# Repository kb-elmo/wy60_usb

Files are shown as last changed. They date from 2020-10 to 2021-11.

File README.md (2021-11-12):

# WY-60 USB

[][cc-by-nc-sa]
<a href="https://ko-fi.com/kb_elmo">kofibadge</a>

## This project is completed and will not get updated anymore.

### QMK compatible drop-in replacement PCB for the Wyse ASCII WY-60 keyboard
The PCB is built entirely with THT parts to keep a somewhat "vintage" look to it and it uses the fullsize 40-pin DIP package ATmega32A.
The controller is placed in the exact same location as the one on the original PCB.




### Partslist
 |Count|Part|
 |-|-|
 |1|ATmega32A 40 pin DIP (32L works too)|
 |1|40 pin DIP socket (optional but highly recommended)|
 |1|2x3 pin header 2.54mm (for ISP flashing)|
 |1|USB Mini port 5pin THT|
 |1|500 mA polyfuse|
 |2|6mm momentary push buttons|
 |1|16 MHz quarz crystal|
 |1|4.7 uF electrolytic capacitor|
 |2|100 nF ceramic disk capacitor|
 |2|22 pF ceramic disk capacitor|
 |1|10 kΩ resistor|
 |2|68 Ω resistor|
 |1|1.5 kΩ resistor|
 |2|3.6 V zener diode (DO-35 BZX55C3V6)|
 |101|universal switching diode (DO-35 1N4148)|

#### Some pictures of the first finished PCB
(https://i.imgur.com/SexuyVJ.jpg) (https://i.imgur.com/DevIs6e.jpg)
(https://i.imgur.com/V66OB8a.jpg) (https://i.imgur.com/2M1VHWP.jpg)
(https://i.imgur.com/meGhRla.jpg) (https://i.imgur.com/xnp9PsB.jpg)

The Case requires some modification to make the new USB port fit.  
Unfortunately the original cable cutout sits in a position where it was not possible to use it for the USB port.

---
This work is licensed under a
[Creative Commons Attribution-NonCommercial-ShareAlike 4.0 International License][cc-by-nc-sa].

[][cc-by-nc-sa]

[cc-by-nc-sa]: http://creativecommons.org/licenses/by-nc-sa/4.0/
[cc-by-nc-sa-image]: https://licensebuttons.net/l/by-nc-sa/4.0/88x31.png
[cc-by-nc-sa-shield]: https://img.shields.io/badge/License-CC%20BY--NC--SA%204.0-lightgrey.svg

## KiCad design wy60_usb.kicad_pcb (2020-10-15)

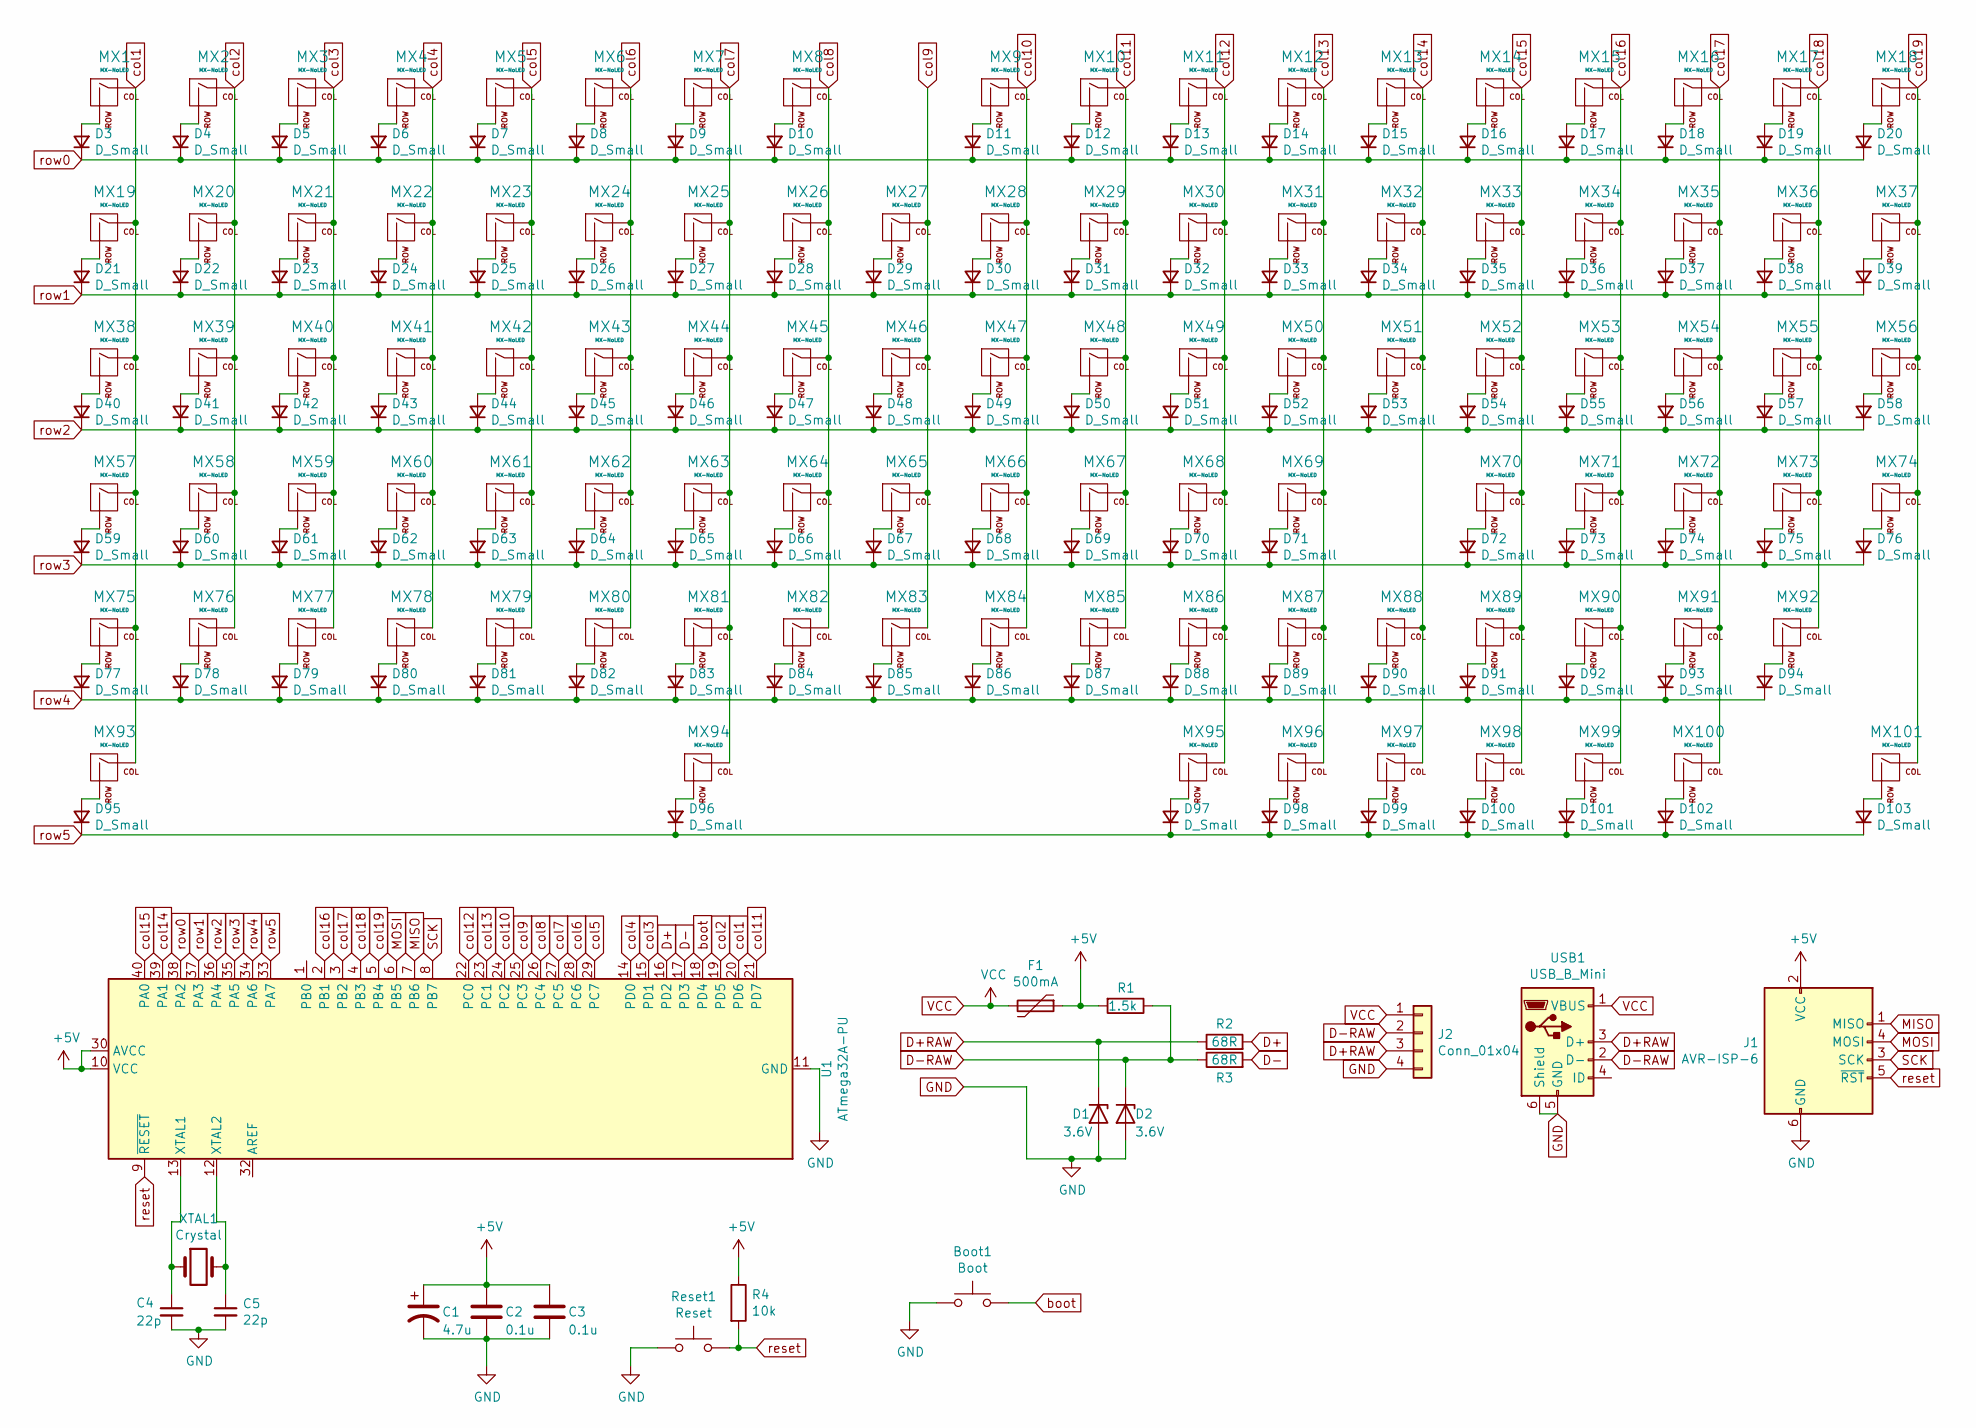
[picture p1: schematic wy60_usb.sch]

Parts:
Boot1: Boot; SW_PUSH_6mm
C1: 4.7u; CP_Radial_D4.0mm_P1.50mm
C2, C3: 0.1u; C_Disc_D3.0mm_W2.0mm_P2.50mm
C4, C5: 22p; C_Disc_D6.0mm_W2.5mm_P5.00mm
D1, D2: 3.6V; D_DO-35_SOD27_P7.62mm_Horizontal
D3, D4, D5, D6, D7, D8, D9, D10, D11, D12, D13, D14, D15, D16, D17, D18, D19, D20, D21, D22, D23, D24, D25, D26, D27, D28, D29, D30, D31, D32, D33, D34, D35, D36, D37, D38, D39, D40, D41, D42, D43, D44, D45, D46, D47, D48, D49, D50, D51, D52, D53, D54, D55, D56, D57, D58, D59, D60, D61, D62, D63, D64, D65, D66, D67, D68, D69, D70, D71, D72, D73, D74, D75, D76, D77, D78, D79, D80, D81, D82, D83, D84, D85, D86, D87, D88, D89, D90, D91, D92, D93, D94, D95, D96, D97, D98, D99, D100, D101, D102, D103: D_Small; D_DO-35_SOD27_P7.62mm_Horizontal
F1: 500mA; Fuse_Littelfuse_395Series
J1: AVR-ISP-6; PinHeader_2x03_P2.54mm_Horizontal
J2: Conn_01x04; JST_PH_S4B-PH-K_1x04_P2.00mm_Horizontal
MX1, MX2, MX3, MX4, MX5, MX6, MX7, MX8, MX9, MX10, MX11, MX12, MX13, MX14, MX15, MX16, MX17, MX18, MX19, MX20, MX21, MX22, MX23, MX24, MX25, MX26, MX27, MX28, MX29, MX30, MX31, MX33, MX34, MX35, MX36, MX37, MX39, MX40, MX41, MX42, MX43, MX44, MX45, MX46, MX47, MX48, MX49, MX50, MX51, MX53, MX54, MX55, MX56, MX58, MX59, MX60, MX61, MX62, MX63, MX64, MX65, MX66, MX67, MX68, MX70, MX71, MX72, MX73, MX74, MX75, MX77, MX78, MX79, MX80, MX81, MX82, MX83, MX84, MX85, MX86, MX88, MX89, MX90, MX91, MX92, MX95, MX96, MX97, MX98, MX100: MX-NoLED; MXOnly-1U-NoLED
MX32, MX57: MX-NoLED; MXOnly-1.75U-NoLED
MX38, MX87: MX-NoLED; MXOnly-1.5U-NoLED
MX52, MX76: MX-NoLED; MXOnly-1.25U-NoLED
MX69, MX93, MX99, MX101: MX-NoLED; MXOnly-2U-NoLED-NoStabilizer
MX94: MX-NoLED; MXOnly-9U-NoLED
R1: 1.5k; R_Axial_DIN0207_L6.3mm_D2.5mm_P10.16mm_Horizontal
R2, R3: 68R; R_Axial_DIN0207_L6.3mm_D2.5mm_P10.16mm_Horizontal
R4: 10k; R_Axial_DIN0207_L6.3mm_D2.5mm_P10.16mm_Horizontal
Reset1: Reset; SW_PUSH_6mm
U1: ATmega32A-PU; DIP-40_W15.24mm_Socket
USB1: USB_B_Mini; USB_Mini
XTAL1: Crystal; Crystal_HC49-4H_Vertical

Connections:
+5V: C1.1, C2.1, C3.1, F1.1, J1.2 (VCC), R1.2, R4.1, U1.10 (VCC), U1.30 (AVCC)
D+: R2.2, U1.16 (PD2)
D+RAW: D1.1 (K), J2.3, R2.1, USB1.3 (D+)
D-: R3.2, U1.17 (PD3)
D-RAW: D2.1 (K), J2.2, R1.1, R3.1, USB1.2 (D-)
GND: Boot1.1, C1.2, C2.2, C3.2, C4.2, C5.2, D1.2 (A), D2.2 (A), J1.6 (GND), J2.4, Reset1.1, U1.11 (GND), U1.31 (GND), USB1.5 (GND), USB1.6 (Shield)
MISO: J1.1 (MISO), U1.7 (PB6)
MOSI: J1.4 (MOSI), U1.6 (PB5)
unnamed: C4.1, U1.13 (XTAL1), XTAL1.1
unnamed: C5.1, U1.12 (XTAL2), XTAL1.2
unnamed: D3.2 (A), MX1.2 (ROW)
unnamed: D4.2 (A), MX2.2 (ROW)
unnamed: D5.2 (A), MX3.2 (ROW)
unnamed: D6.2 (A), MX4.2 (ROW)
unnamed: D7.2 (A), MX5.2 (ROW)
unnamed: D8.2 (A), MX6.2 (ROW)
unnamed: D9.2 (A), MX7.2 (ROW)
unnamed: D10.2 (A), MX8.2 (ROW)
unnamed: D11.2 (A), MX9.2 (ROW)
unnamed: D12.2 (A), MX10.2 (ROW)
unnamed: D13.2 (A), MX11.2 (ROW)
unnamed: D14.2 (A), MX12.2 (ROW)
unnamed: D15.2 (A), MX13.2 (ROW)
unnamed: D16.2 (A), MX14.2 (ROW)
unnamed: D17.2 (A), MX15.2 (ROW)
unnamed: D18.2 (A), MX16.2 (ROW)
unnamed: D19.2 (A), MX17.2 (ROW)
unnamed: D20.2 (A), MX18.2 (ROW)
unnamed: D21.2 (A), MX19.2 (ROW)
unnamed: D22.2 (A), MX20.2 (ROW)
unnamed: D23.2 (A), MX21.2 (ROW)
unnamed: D24.2 (A), MX22.2 (ROW)
unnamed: D25.2 (A), MX23.2 (ROW)
unnamed: D26.2 (A), MX24.2 (ROW)
unnamed: D27.2 (A), MX25.2 (ROW)
unnamed: D28.2 (A), MX26.2 (ROW)
unnamed: D29.2 (A), MX27.2 (ROW)
unnamed: D30.2 (A), MX28.2 (ROW)
unnamed: D31.2 (A), MX29.2 (ROW)
unnamed: D32.2 (A), MX30.2 (ROW)
unnamed: D33.2 (A), MX31.2 (ROW)
unnamed: D34.2 (A), MX32.2 (ROW)
unnamed: D35.2 (A), MX33.2 (ROW)
unnamed: D36.2 (A), MX34.2 (ROW)
unnamed: D37.2 (A), MX35.2 (ROW)
unnamed: D38.2 (A), MX36.2 (ROW)
unnamed: D39.2 (A), MX37.2 (ROW)
unnamed: D40.2 (A), MX38.2 (ROW)
unnamed: D41.2 (A), MX39.2 (ROW)
unnamed: D42.2 (A), MX40.2 (ROW)
unnamed: D43.2 (A), MX41.2 (ROW)
unnamed: D44.2 (A), MX42.2 (ROW)
unnamed: D45.2 (A), MX43.2 (ROW)
unnamed: D46.2 (A), MX44.2 (ROW)
unnamed: D47.2 (A), MX45.2 (ROW)
unnamed: D48.2 (A), MX46.2 (ROW)
unnamed: D49.2 (A), MX47.2 (ROW)
unnamed: D50.2 (A), MX48.2 (ROW)
unnamed: D51.2 (A), MX49.2 (ROW)
unnamed: D52.2 (A), MX50.2 (ROW)
unnamed: D53.2 (A), MX51.2 (ROW)
unnamed: D54.2 (A), MX52.2 (ROW)
unnamed: D55.2 (A), MX53.2 (ROW)
unnamed: D56.2 (A), MX54.2 (ROW)
unnamed: D57.2 (A), MX55.2 (ROW)
unnamed: D58.2 (A), MX56.2 (ROW)
unnamed: D59.2 (A), MX57.2 (ROW)
unnamed: D60.2 (A), MX58.2 (ROW)
unnamed: D61.2 (A), MX59.2 (ROW)
unnamed: D62.2 (A), MX60.2 (ROW)
unnamed: D63.2 (A), MX61.2 (ROW)
unnamed: D64.2 (A), MX62.2 (ROW)
unnamed: D65.2 (A), MX63.2 (ROW)
unnamed: D66.2 (A), MX64.2 (ROW)
unnamed: D67.2 (A), MX65.2 (ROW)
unnamed: D68.2 (A), MX66.2 (ROW)
unnamed: D69.2 (A), MX67.2 (ROW)
unnamed: D70.2 (A), MX68.2 (ROW)
unnamed: D71.2 (A), MX69.2 (ROW)
unnamed: D72.2 (A), MX70.2 (ROW)
unnamed: D73.2 (A), MX71.2 (ROW)
unnamed: D74.2 (A), MX72.2 (ROW)
unnamed: D75.2 (A), MX73.2 (ROW)
unnamed: D76.2 (A), MX74.2 (ROW)
unnamed: D77.2 (A), MX75.2 (ROW)
unnamed: D78.2 (A), MX76.2 (ROW)
unnamed: D79.2 (A), MX77.2 (ROW)
unnamed: D80.2 (A), MX78.2 (ROW)
unnamed: D81.2 (A), MX79.2 (ROW)
unnamed: D82.2 (A), MX80.2 (ROW)
unnamed: D83.2 (A), MX81.2 (ROW)
unnamed: D84.2 (A), MX82.2 (ROW)
unnamed: D85.2 (A), MX83.2 (ROW)
unnamed: D86.2 (A), MX84.2 (ROW)
unnamed: D87.2 (A), MX85.2 (ROW)
unnamed: D88.2 (A), MX86.2 (ROW)
unnamed: D89.2 (A), MX87.2 (ROW)
unnamed: D90.2 (A), MX88.2 (ROW)
unnamed: D91.2 (A), MX89.2 (ROW)
unnamed: D92.2 (A), MX90.2 (ROW)
unnamed: D93.2 (A), MX91.2 (ROW)
unnamed: D94.2 (A), MX92.2 (ROW)
unnamed: D95.2 (A), MX93.2 (ROW)
unnamed: D96.2 (A), MX94.2 (ROW)
unnamed: D97.2 (A), MX95.2 (ROW)
unnamed: D98.2 (A), MX96.2 (ROW)
unnamed: D99.2 (A), MX97.2 (ROW)
unnamed: D100.2 (A), MX98.2 (ROW)
unnamed: D101.2 (A), MX99.2 (ROW)
unnamed: D102.2 (A), MX100.2 (ROW)
unnamed: D103.2 (A), MX101.2 (ROW)
SCK: J1.3 (SCK), U1.8 (PB7)
VCC: F1.2, J2.1, USB1.1 (VBUS)
boot: Boot1.2, U1.18 (PD4)
col1: MX1.1 (COL), MX19.1 (COL), MX38.1 (COL), MX57.1 (COL), MX75.1 (COL), MX93.1 (COL), U1.20 (PD6)
col2: MX2.1 (COL), MX20.1 (COL), MX39.1 (COL), MX58.1 (COL), MX76.1 (COL), U1.19 (PD5)
col3: MX3.1 (COL), MX21.1 (COL), MX40.1 (COL), MX59.1 (COL), MX77.1 (COL), U1.15 (PD1)
col4: MX4.1 (COL), MX22.1 (COL), MX41.1 (COL), MX60.1 (COL), MX78.1 (COL), U1.14 (PD0)
col5: MX5.1 (COL), MX23.1 (COL), MX42.1 (COL), MX61.1 (COL), MX79.1 (COL), U1.29 (PC7)
col6: MX6.1 (COL), MX24.1 (COL), MX43.1 (COL), MX62.1 (COL), MX80.1 (COL), U1.28 (PC6)
col7: MX7.1 (COL), MX25.1 (COL), MX44.1 (COL), MX63.1 (COL), MX81.1 (COL), MX94.1 (COL), U1.27 (PC5)
col8: MX8.1 (COL), MX26.1 (COL), MX45.1 (COL), MX64.1 (COL), MX82.1 (COL), U1.26 (PC4)
col9: MX27.1 (COL), MX46.1 (COL), MX65.1 (COL), MX83.1 (COL), U1.25 (PC3)
col10: MX9.1 (COL), MX28.1 (COL), MX47.1 (COL), MX66.1 (COL), MX84.1 (COL), U1.24 (PC2)
col11: MX10.1 (COL), MX29.1 (COL), MX48.1 (COL), MX67.1 (COL), MX85.1 (COL), U1.21 (PD7)
col12: MX11.1 (COL), MX30.1 (COL), MX49.1 (COL), MX68.1 (COL), MX86.1 (COL), MX95.1 (COL), U1.22 (PC0)
col13: MX12.1 (COL), MX31.1 (COL), MX50.1 (COL), MX69.1 (COL), MX87.1 (COL), MX96.1 (COL), U1.23 (PC1)
col14: MX13.1 (COL), MX32.1 (COL), MX51.1 (COL), MX88.1 (COL), MX97.1 (COL), U1.39 (PA1)
col15: MX14.1 (COL), MX33.1 (COL), MX52.1 (COL), MX70.1 (COL), MX89.1 (COL), MX98.1 (COL), U1.40 (PA0)
col16: MX15.1 (COL), MX34.1 (COL), MX53.1 (COL), MX71.1 (COL), MX90.1 (COL), MX99.1 (COL), U1.2 (PB1)
col17: MX16.1 (COL), MX35.1 (COL), MX54.1 (COL), MX72.1 (COL), MX91.1 (COL), MX100.1 (COL), U1.3 (PB2)
col18: MX17.1 (COL), MX36.1 (COL), MX55.1 (COL), MX73.1 (COL), MX92.1 (COL), U1.4 (PB3)
col19: MX18.1 (COL), MX37.1 (COL), MX56.1 (COL), MX74.1 (COL), MX101.1 (COL), U1.5 (PB4)
reset: J1.5 (~RST), R4.2, Reset1.2, U1.9 (~RESET)
row0: D3.1 (K), D4.1 (K), D5.1 (K), D6.1 (K), D7.1 (K), D8.1 (K), D9.1 (K), D10.1 (K), D11.1 (K), D12.1 (K), D13.1 (K), D14.1 (K), D15.1 (K), D16.1 (K), D17.1 (K), D18.1 (K), D19.1 (K), D20.1 (K), U1.38 (PA2)
row1: D21.1 (K), D22.1 (K), D23.1 (K), D24.1 (K), D25.1 (K), D26.1 (K), D27.1 (K), D28.1 (K), D29.1 (K), D30.1 (K), D31.1 (K), D32.1 (K), D33.1 (K), D34.1 (K), D35.1 (K), D36.1 (K), D37.1 (K), D38.1 (K), D39.1 (K), U1.37 (PA3)
row2: D40.1 (K), D41.1 (K), D42.1 (K), D43.1 (K), D44.1 (K), D45.1 (K), D46.1 (K), D47.1 (K), D48.1 (K), D49.1 (K), D50.1 (K), D51.1 (K), D52.1 (K), D53.1 (K), D54.1 (K), D55.1 (K), D56.1 (K), D57.1 (K), D58.1 (K), U1.36 (PA4)
row3: D59.1 (K), D60.1 (K), D61.1 (K), D62.1 (K), D63.1 (K), D64.1 (K), D65.1 (K), D66.1 (K), D67.1 (K), D68.1 (K), D69.1 (K), D70.1 (K), D71.1 (K), D72.1 (K), D73.1 (K), D74.1 (K), D75.1 (K), D76.1 (K), U1.35 (PA5)
row4: D77.1 (K), D78.1 (K), D79.1 (K), D80.1 (K), D81.1 (K), D82.1 (K), D83.1 (K), D84.1 (K), D85.1 (K), D86.1 (K), D87.1 (K), D88.1 (K), D89.1 (K), D90.1 (K), D91.1 (K), D92.1 (K), D93.1 (K), D94.1 (K), U1.34 (PA6)
row5: D95.1 (K), D96.1 (K), D97.1 (K), D98.1 (K), D99.1 (K), D100.1 (K), D101.1 (K), D102.1 (K), D103.1 (K), U1.33 (PA7)

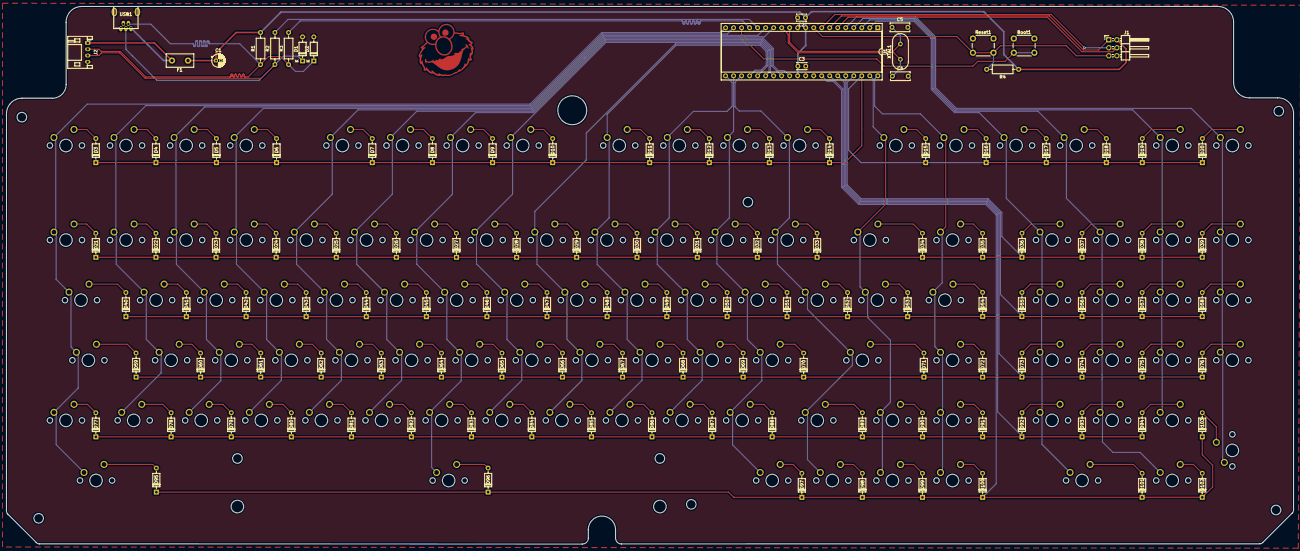
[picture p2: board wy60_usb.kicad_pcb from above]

Board: 2 copper layers, 407.9 x 170.4 mm, 221 parts (0 on the bottom side), 140 nets.

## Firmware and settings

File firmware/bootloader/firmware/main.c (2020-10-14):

/* Name: main.c
 * Project: USBaspLoader
 * Author: Christian Starkjohann
 * Author: Stephan Baerwolf
 * Creation Date: 2007-12-08
 * Modification Date: 2013-03-31
 * Tabsize: 4
 * Copyright: (c) 2007 by OBJECTIVE DEVELOPMENT Software GmbH
 * License: GNU GPL v2 (see License.txt)
 */

#include "spminterface.h"  /* must be included as first! */

#include "../misc/iofixes.h"

#include <avr/interrupt.h>
#include <avr/pgmspace.h>
#include <avr/wdt.h>
#include <avr/boot.h>
#include <avr/eeprom.h>
#include <util/delay.h>


#if 0
/*
 * 29.09.2012 /  30.09.2012
 * 
 * Since cpufunc.h is not needed in this context and
 * since it is not available in all toolchains, this include
 * becomes deactivated by github issue-report.
 * (In case of trouble it remains in sourcecode for reactivation.)
 * 
 * The autor would like to thank Lena-M for reporting this
 * issue (https://github.com/baerwolf/USBaspLoader/issues/1).
 */
#include <avr/cpufunc.h>
#endif

#include <avr/boot.h>

#include <string.h>



#include "bootloaderconfig.h"

#include "usbdrv/usbdrv.c"
static usbMsgLen_t usbFunctionDescriptor(struct usbRequest *rq) {
  return 0;
}

#ifndef BOOTLOADER_ADDRESS
  #error need to know the bootloaders flash address!
#endif
#define BOOTLOADER_PAGEADDR	(BOOTLOADER_ADDRESS - (BOOTLOADER_ADDRESS % SPM_PAGESIZE))

/* ------------------------------------------------------------------------ */

/* Request constants used by USBasp */
#define USBASP_FUNC_CONNECT         1
#define USBASP_FUNC_DISCONNECT      2
#define USBASP_FUNC_TRANSMIT        3
#define USBASP_FUNC_READFLASH       4
#define USBASP_FUNC_ENABLEPROG      5
#define USBASP_FUNC_WRITEFLASH      6
#define USBASP_FUNC_READEEPROM      7
#define USBASP_FUNC_WRITEEEPROM     8
#define USBASP_FUNC_SETLONGADDRESS  9

// additional USBasp Commands
#define USBASP_FUNC_SETISPSCK	     10
#define USBASP_FUNC_TPI_CONNECT      11
#define USBASP_FUNC_TPI_DISCONNECT   12
#define USBASP_FUNC_TPI_RAWREAD      13
#define USBASP_FUNC_TPI_RAWWRITE     14
#define USBASP_FUNC_TPI_READBLOCK    15
#define USBASP_FUNC_TPI_WRITEBLOCK   16
#define USBASP_FUNC_GETCAPABILITIES 127
/* ------------------------------------------------------------------------ */

#ifndef ulong
#   define ulong    unsigned long
#endif
#ifndef uint
#   define uint     unsigned int
#endif


/* allow compatibility with avrusbboot's bootloaderconfig.h: */
#ifdef BOOTLOADER_INIT
#   define bootLoaderInit()         BOOTLOADER_INIT
#   define bootLoaderExit()
#endif
#ifdef BOOTLOADER_CONDITION
#   define bootLoaderCondition()    BOOTLOADER_CONDITION
#endif

/* device compatibility: */
#ifndef GICR    /* ATMega*8 don't have GICR, use MCUCR instead */
#   define GICR     MCUCR
#endif

/* ------------------------------------------------------------------------ */

#if (FLASHEND) > 0xffff /* we need long addressing */
#   define CURRENT_ADDRESS  currentAddress.l
#   define addr_t           ulong
#else
#   define CURRENT_ADDRESS  currentAddress.w[0]
#   define addr_t           uint
#endif

typedef union longConverter{
    addr_t  l;
    uint    w[sizeof(addr_t)/2];
    uchar   b[sizeof(addr_t)];
}longConverter_t;


#define __IMPLEMENT_PRESERVE_WATCHDOG	((PRESERVE_WATCHDOG) && (!(USE_EXCESSIVE_ASSEMBLER)) && ((NEED_WATCHDOG) || (defined(__MCUCSR_COMPATMODE))))
#if (__IMPLEMENT_PRESERVE_WATCHDOG)
static uint8_t __original_WDTCR;
#endif

#if (BOOTLOADER_CAN_EXIT)
#	if (BOOTLOADER_LOOPCYCLES_TIMEOUT)
#		if (BOOTLOADER_LOOPCYCLES_TIMEOUT < 256)
#			if ((HAVE_UNPRECISEWAIT))
	 register uint8_t timeout_remaining __asm__("r2");
#			else
static volatile uint8_t timeout_remaining;
#			endif
#		else
static volatile uint16_t timeout_remaining;
#		endif
#	endif

#	define stayinloader_initialValue 0xfe
#	if ((HAVE_UNPRECISEWAIT))
/* here we have to assume we need to optimize for every byte */
	 register uint8_t stayinloader __asm__("r17");
#	else
static volatile uint8_t stayinloader;
#	endif
#endif

static longConverter_t  	currentAddress; /* in bytes */
static uchar            	bytesRemaining;
static uchar            	isLastPage;
#if HAVE_EEPROM_PAGED_ACCESS
static uchar            	currentRequest;
#else
static const uchar      	currentRequest = 0;
#endif

static const uchar  signatureBytes[4] = {
#ifdef SIGNATURE_BYTES
    SIGNATURE_BYTES
#elif defined (__AVR_ATmega8535__)
    0x1e, 0x93, 0x08, 0
#elif defined (__AVR_ATmega8__) || defined (__AVR_ATmega8A__) || defined (__AVR_ATmega8HVA__)
    0x1e, 0x93, 0x07, 0
#elif defined (__AVR_ATmega16__)
    0x1e, 0x94, 0x03, 0
#elif defined (__AVR_ATmega32__)
    0x1e, 0x95, 0x02, 0
#elif defined (__AVR_ATmega48__) || defined (__AVR_ATmega48A__)
    #error ATmega48 does not support bootloaders!
    0x1e, 0x92, 0x05, 0
#elif defined (__AVR_ATmega48PA__) || defined (__AVR_ATmega48P__)
    #error ATmega48P does not support bootloaders!
    0x1e, 0x92, 0x0A, 0
#elif defined (__AVR_ATmega88__) || defined (__AVR_ATmega88A__)
    0x1e, 0x93, 0x0a, 0
#elif defined (__AVR_ATmega88PA__) || defined (__AVR_ATmega88P__)
    0x1e, 0x93, 0x0F, 0
#elif defined (__AVR_ATmega162__)
    0x1e, 0x94, 0x04, 0
#elif defined (__AVR_ATmega164A__)
    0x1e, 0x94, 0x0f, 0
#elif defined (__AVR_ATmega164P__) || defined (__AVR_ATmega164PA__)
    0x1e, 0x94, 0x0a, 0
#elif defined (__AVR_ATmega168__) || defined (__AVR_ATmega168A__)
    0x1e, 0x94, 0x06, 0
#elif defined (__AVR_ATmega168PA__) || defined (__AVR_ATmega168P__)
    0x1e, 0x94, 0x0B, 0
#elif defined (__AVR_ATmega324A__)
    0x1e, 0x95, 0x15, 0
#elif defined (__AVR_ATmega324P__)
    0x1e, 0x95, 0x08, 0
#elif defined (__AVR_ATmega324PA__)
    0x1e, 0x95, 0x11, 0
#elif defined (__AVR_ATmega328__)
    0x1e, 0x95, 0x14, 0
#elif defined (__AVR_ATmega328P__)
    0x1e, 0x95, 0x0f, 0
#elif defined (__AVR_ATmega640__)
    0x1e, 0x96, 0x08, 0
#elif defined (__AVR_ATmega644__) || defined (__AVR_ATmega644A__)
    0x1e, 0x96, 0x09, 0
#elif defined (__AVR_ATmega644P__) || defined (__AVR_ATmega644PA__)
    0x1e, 0x96, 0x0a, 0
#elif defined (__AVR_ATmega128__)
    0x1e, 0x97, 0x02, 0
#elif defined (__AVR_ATmega1280__)
    0x1e, 0x97, 0x03, 0
#elif defined (__AVR_ATmega1281__)
    0x1e, 0x97, 0x04, 0
#elif defined (__AVR_ATmega1284__)
    0x1e, 0x97, 0x06, 0
#elif defined (__AVR_ATmega1284P__)
    0x1e, 0x97, 0x05, 0
#elif defined (__AVR_ATmega2560__)
    0x1e, 0x98, 0x01, 0
#elif defined (__AVR_ATmega2561__)
    0x1e, 0x98, 0x02, 0
#else
#   if (defined(SIGNATURE_0) && defined(SIGNATURE_1) && defined(SIGNATURE_2))
#     warning "Device signature is not known - using AVR Libc suggestion..."
    SIGNATURE_0, SIGNATURE_1, SIGNATURE_2, 0
#   else
#     error "Device signature is not known, please edit main.c!"
#   endif
#endif
};

/* ------------------------------------------------------------------------ */

#if (HAVE_BOOTLOADERENTRY_FROMSOFTWARE)
void __attribute__ ((section(".init3"),naked,used,no_instrument_function)) __BOOTLOADERENTRY_FROMSOFTWARE__bootup_investigate_RAMEND(void);
void __BOOTLOADERENTRY_FROMSOFTWARE__bootup_investigate_RAMEND(void) {
  asm volatile (
    "in		%[mcucsrval]	,	%[mcucsrio]\n\t"
    "ldi	r29		,	%[ramendhi]\n\t"
    "ldi	r28		,	%[ramendlo]\n\t"
#if (FLASHEND>131071)
    "ld		%[result]	,	Y+\n\t"
    "cpi	%[result]	,	%[bootaddrhi]\n\t"
    "brne	__BOOTLOADERENTRY_FROMSOFTWARE__bootup_investigate_RAMEND_mismatch%=\n\t"
#endif
    "ld		%[result]	,	Y+\n\t"
    "cpi	%[result]	,	%[bootaddrme]\n\t"
    "ld		%[result]	,	Y+\n\t"
    "breq	__BOOTLOADERENTRY_FROMSOFTWARE__bootup_investigate_RAMEND_done%=\n\t"

    "__BOOTLOADERENTRY_FROMSOFTWARE__bootup_investigate_RAMEND_mismatch%=:\n\t"
    "ldi	%[result]	,	0xff\n\t"

    "__BOOTLOADERENTRY_FROMSOFTWARE__bootup_investigate_RAMEND_done%=:\n\t"
    : [result]		"=a" (__BOOTLOADERENTRY_FROMSOFTWARE__bootup_RAMEND_doesmatch),
      [mcucsrval]	"=a" (__BOOTLOADERENTRY_FROMSOFTWARE__bootup_MCUCSR)
    : [mcucsrio]	"I"  (_SFR_IO_ADDR(MCUCSR)),
#if (FLASHEND>131071)
      [ramendhi]	"M" (((RAMEND - 2) >> 8) & 0xff),
      [ramendlo]	"M" (((RAMEND - 2) >> 0) & 0xff),
      [bootaddrhi]	"M" (((__BOOTLOADERENTRY_FROMSOFTWARE__EXPECTEDADDRESS) >>16) & 0xff),
#else
      [ramendhi]	"M" (((RAMEND - 1) >> 8) & 0xff),
      [ramendlo]	"M" (((RAMEND - 1) >> 0) & 0xff),
#endif
      [bootaddrme]	"M" (((__BOOTLOADERENTRY_FROMSOFTWARE__EXPECTEDADDRESS) >> 8) & 0xff)
    
  );
}
#endif

#if (USE_BOOTUP_CLEARRAM)
/*
* Under normal circumstances, RESET will not clear contents of RAM.
* As always, if you want it done - do it yourself...
*/
void __attribute__ ((section(".init3"),naked,used,no_instrument_function)) __func_clearram(void);
void __func_clearram(void) {
  extern size_t __bss_end;
  asm volatile (
    "__clearram:\n\t"
#if (!(HAVE_BOOTLOADERENTRY_FROMSOFTWARE))
    "ldi r29, %[ramendhi]\n\t"
    "ldi r28, %[ramendlo]\n\t"
#endif
    "__clearramloop%=:\n\t"
    "st -Y , __zero_reg__\n\t"
    "cp r28, %A[bssend]\n\t"
    "cpc r29, %B[bssend]\n\t"
    "brne __clearramloop%=\n\t"
    :
    : [ramendhi] "M" (((RAMEND+1)>>8) & 0xff),
      [ramendlo] "M" (((RAMEND+1)>>0) & 0xff),
      [bssend] "r" (&__bss_end)
    : "memory"
      );
}
#endif

#if (!USE_EXCESSIVE_ASSEMBLER) || (!(defined (__AVR_ATmega8__) || defined (__AVR_ATmega8A__) || defined (__AVR_ATmega8HVA__)))
static void (*nullVector)(void) __attribute__((__noreturn__));
#endif

#if (USE_EXCESSIVE_ASSEMBLER) && (defined (__AVR_ATmega8__) || defined (__AVR_ATmega8A__) || defined (__AVR_ATmega8HVA__))
static void __attribute__((naked,__noreturn__)) leaveBootloader(void);
static void leaveBootloader(void) {
  asm  volatile  (
  "cli\n\t"
  "sbi		%[usbddr],	%[usbminus]\n\t"  
  "cbi		%[port],	%[bit]\n\t"
  "out		%[usbintrenab],	__zero_reg__\n\t"
  "out		%[usbintrcfg],	__zero_reg__\n\t"
  "ldi		r31,		%[ivce]\n\t"
  "out		%[mygicr],	r31\n\t"
  "out		%[mygicr],	__zero_reg__\n\t"  
  "rjmp		nullVector\n\t"
  :
  : [port]        "I" (_SFR_IO_ADDR(PIN_PORT(JUMPER_PORT))),
    [bit]         "I" (PIN(JUMPER_PORT, JUMPER_BIT)),
    [usbintrenab] "I" (_SFR_IO_ADDR(USB_INTR_ENABLE)),
    [usbintrcfg]  "I" (_SFR_IO_ADDR(USB_INTR_CFG)),
    [usbddr]      "I" (_SFR_IO_ADDR(USBDDR)),
    [usbminus]    "I" (USBMINUS),
    [mygicr]      "I" (_SFR_IO_ADDR(GICR)),	      
    [ivce]        "I" (1<<IVCE)
);
}
#else
static void __attribute__((__noreturn__)) leaveBootloader(void);
static void leaveBootloader(void) {
    DBG1(0x01, 0, 0);
    cli();
    usbDeviceDisconnect();
    bootLoaderExit();
    USB_INTR_ENABLE = 0;
    USB_INTR_CFG = 0;       /* also reset config bits */
    GICR = (1 << IVCE);     /* enable change of interrupt vectors */
    GICR = (0 << IVSEL);    /* move interrupts to application flash section */

/* restore the original watchdog timer if necessary */
#if (__IMPLEMENT_PRESERVE_WATCHDOG)
    if (__original_WDTCR & _BV(WDE)) {
      __original_WDTCR &= ~(_BV(WDCE));
      wdt_reset();
      WDTCR |= (_BV(WDCE)) | (_BV(WDE));
      WDTCR  = __original_WDTCR;
      wdt_reset();
    }
#endif
/*
 * There seems to be another funny compiler Bug.
 * When gcc is using "eicall" opcode it forgets to modify EIND.
 * On devices with large flash memory there are some target address bits
 * missing. In this case some zero bits...
 */
#if (defined(EIND) && ((FLASHEND)>131071))
  EIND=0;
#endif
/* We must go through a global function pointer variable instead of writing
 *  ((void (*)(void))0)();
 * because the compiler optimizes a constant 0 to "rcall 0" which is not
 * handled correctly by the assembler.
 */
    nullVector();
}
#endif

/* ------------------------------------------------------------------------ */


uchar usbFunctionSetup_USBASP_FUNC_TRANSMIT(usbRequest_t *rq) {
  uchar rval = 0;
  usbWord_t address;
  address.bytes[1] = rq->wValue.bytes[1];
  address.bytes[0] = rq->wIndex.bytes[0];

  if(rq->wValue.bytes[0] == 0x30){        /* read signature */
    rval = rq->wIndex.bytes[0] & 3;
    rval = signatureBytes[rval];
#if HAVE_READ_LOCK_FUSE
#if defined (__AVR_ATmega8535__) || 					\
    defined (__AVR_ATmega8__) || defined (__AVR_ATmega8A__) || 		\
    defined (__AVR_ATmega16__) || defined (__AVR_ATmega32__)
  }else if(rq->wValue.bytes[0] == 0x58 && rq->wValue.bytes[1] == 0x00){  /* read lock bits */
      rval = boot_lock_fuse_bits_get(GET_LOCK_BITS);
  }else if(rq->wValue.bytes[0] == 0x50 && rq->wValue.bytes[1] == 0x00){  /* read lfuse bits */
      rval = boot_lock_fuse_bits_get(GET_LOW_FUSE_BITS);
  }else if(rq->wValue.bytes[0] == 0x58 && rq->wValue.bytes[1] == 0x08){  /* read hfuse bits */
      rval = boot_lock_fuse_bits_get(GET_HIGH_FUSE_BITS);

#elif defined (__AVR_ATmega48__)   || defined (__AVR_ATmega48A__)   || defined (__AVR_ATmega48P__)   || defined (__AVR_ATmega48PA__)  ||  \
defined (__AVR_ATmega88__)   || defined (__AVR_ATmega88A__)   || defined (__AVR_ATmega88P__)   || defined (__AVR_ATmega88PA__)  ||  \
defined (__AVR_ATmega162__)  || 												      \
defined (__AVR_ATmega164A__) || defined (__AVR_ATmega164P__)  || 								      \
defined (__AVR_ATmega168__)  || defined (__AVR_ATmega168A__)  || defined (__AVR_ATmega168P__)  || defined (__AVR_ATmega168PA__) ||  \
defined (__AVR_ATmega324A__) || defined (__AVR_ATmega324P__)  ||								      \
defined (__AVR_ATmega328__)  || defined (__AVR_ATmega328P__)  ||								      \
defined (__AVR_ATmega640__)  ||													\
defined (__AVR_ATmega644__)  || defined (__AVR_ATmega644A__)  || defined (__AVR_ATmega644P__) || defined (__AVR_ATmega644PA__)  ||  \
defined (__AVR_ATmega128__)  ||													      \
defined (__AVR_ATmega1280__) ||													\
defined (__AVR_ATmega1281__) ||													\
defined (__AVR_ATmega1284__) || defined (__AVR_ATmega1284P__)  ||													\
defined (__AVR_ATmega2560__) ||													\
defined (__AVR_ATmega2561__)
  }else if(rq->wValue.bytes[0] == 0x58 && rq->wValue.bytes[1] == 0x00){  /* read lock bits */
      rval = boot_lock_fuse_bits_get(GET_LOCK_BITS);
  }else if(rq->wValue.bytes[0] == 0x50 && rq->wValue.bytes[1] == 0x00){  /* read lfuse bits */
      rval = boot_lock_fuse_bits_get(GET_LOW_FUSE_BITS);
  }else if(rq->wValue.bytes[0] == 0x58 && rq->wValue.bytes[1] == 0x08){  /* read hfuse bits */
      rval = boot_lock_fuse_bits_get(GET_HIGH_FUSE_BITS);
  }else if(rq->wValue.bytes[0] == 0x50 && rq->wValue.bytes[1] == 0x08){  /* read efuse bits */
      rval = boot_lock_fuse_bits_get(GET_EXTENDED_FUSE_BITS );
#else
  #warning "HAVE_READ_LOCK_FUSE is activated but MCU unknown -> will not support this feature"
#endif
#endif
#if HAVE_FLASH_BYTE_READACCESS
  }else if(rq->wValue.bytes[0] == 0x20){  /* read FLASH low  byte */
#if ((FLASHEND) > 65535)
      rval = pgm_read_byte_far((((addr_t)address.word)<<1)+0);
#else
      rval = pgm_read_byte((((addr_t)address.word)<<1)+0);
#endif
  }else if(rq->wValue.bytes[0] == 0x28){  /* read FLASH high byte */
#if ((FLASHEND) > 65535)
      rval = pgm_read_byte_far((((addr_t)address.word)<<1)+1);
#else
      rval = pgm_read_byte((((addr_t)address.word)<<1)+1);
#endif
#endif
#if HAVE_EEPROM_BYTE_ACCESS
  }else if(rq->wValue.bytes[0] == 0xa0){  /* read EEPROM byte */
      rval = eeprom_read_byte((void *)address.word);
  }else if(rq->wValue.bytes[0] == 0xc0){  /* write EEPROM byte */
      eeprom_write_byte((void *)address.word, rq->wIndex.bytes[1]);
#endif
#if HAVE_CHIP_ERASE
  }else if(rq->wValue.bytes[0] == 0xac && rq->wValue.bytes[1] == 0x80){  /* chip erase */
      addr_t addr;
#if HAVE_BLB11_SOFTW_LOCKBIT
      for(addr = 0; addr < (addr_t)(BOOTLOADER_PAGEADDR) ; addr += SPM_PAGESIZE) {
#else
      for(addr = 0; addr <= (addr_t)(FLASHEND) ; addr += SPM_PAGESIZE) {
#endif
	  /* wait and erase page */
	  DBG1(0x33, 0, 0);
#   ifndef NO_FLASH_WRITE
	  boot_spm_busy_wait();
	  cli();
	  boot_page_erase(addr);
	  sei();
#   endif
      }
#endif
#if ((HAVE_BOOTLOADER_HIDDENEXITCOMMAND) && (BOOTLOADER_CAN_EXIT))
#	if ((HAVE_BOOTLOADER_HIDDENEXITCOMMAND != 0xac) && \
	    (HAVE_BOOTLOADER_HIDDENEXITCOMMAND != 0x20) && (HAVE_BOOTLOADER_HIDDENEXITCOMMAND != 0x28) && \
	    (HAVE_BOOTLOADER_HIDDENEXITCOMMAND != 0x40) && (HAVE_BOOTLOADER_HIDDENEXITCOMMAND != 0x48) && \
	    (HAVE_BOOTLOADER_HIDDENEXITCOMMAND != 0x4c) && \
	    (HAVE_BOOTLOADER_HIDDENEXITCOMMAND != 0xa0) && \
	    (HAVE_BOOTLOADER_HIDDENEXITCOMMAND != 0xc0) && \
	    (HAVE_BOOTLOADER_HIDDENEXITCOMMAND != 0x58) && \
	    (HAVE_BOOTLOADER_HIDDENEXITCOMMAND != 0x5c) && \
	    (HAVE_BOOTLOADER_HIDDENEXITCOMMAND != 0x30) && \
	    (HAVE_BOOTLOADER_HIDDENEXITCOMMAND != 0xac) && \
	    (HAVE_BOOTLOADER_HIDDENEXITCOMMAND != 0x50) && (HAVE_BOOTLOADER_HIDDENEXITCOMMAND != 0x58) && \
	    (HAVE_BOOTLOADER_HIDDENEXITCOMMAND != 0x38))
  }else if(rq->wValue.bytes[0] == (HAVE_BOOTLOADER_HIDDENEXITCOMMAND)){  /* cause a bootLoaderExit at disconnect */
      stayinloader = 0xf1;  /* we need to be connected - so assume it */
#	endif
#endif
  }else{
      /* ignore all others, return default value == 0 */
  }
        
  return rval;
}


usbMsgLen_t usbFunctionSetup(uchar data[8])
{
usbRequest_t    *rq = (void *)data;
usbMsgLen_t     len = 0;
static uchar    replyBuffer[4];

    usbMsgPtr = (usbMsgPtr_t)replyBuffer;
    if(rq->bRequest == USBASP_FUNC_TRANSMIT){   /* emulate parts of ISP protocol */
        replyBuffer[3] = usbFunctionSetup_USBASP_FUNC_TRANSMIT(rq);
        len = (usbMsgLen_t)4;
    }else if((rq->bRequest == USBASP_FUNC_ENABLEPROG) || (rq->bRequest == USBASP_FUNC_SETISPSCK)){
        /* replyBuffer[0] = 0; is never touched and thus always 0 which means success */
        len = (usbMsgLen_t)1;
    }else if(rq->bRequest >= USBASP_FUNC_READFLASH && rq->bRequest <= USBASP_FUNC_SETLONGADDRESS){
        currentAddress.w[0] = rq->wValue.word;
        if(rq->bRequest == USBASP_FUNC_SETLONGADDRESS){
#if (FLASHEND) > 0xffff
            currentAddress.w[1] = rq->wIndex.word;
#endif
        }else{
            bytesRemaining = rq->wLength.bytes[0];
            /* if(rq->bRequest == USBASP_FUNC_WRITEFLASH) only evaluated during writeFlash anyway */
            isLastPage = rq->wIndex.bytes[1] & 0x02;
#if HAVE_EEPROM_PAGED_ACCESS
            currentRequest = rq->bRequest;
#endif
            len = USB_NO_MSG; /* hand over to usbFunctionRead() / usbFunctionWrite() */
        }

    }else if(rq->bRequest == USBASP_FUNC_DISCONNECT){

#if BOOTLOADER_CAN_EXIT
#	ifdef CONFIG_HAVE__BOOTLOADER_ABORTTIMEOUTONACT
      /* let the main loop know for ever that here was activity */
      stayinloader	   &= (0xfc);
#	else
      stayinloader	   &= (0xfe);
#	endif
#endif
    }else{
        /* ignore: others, but could be USBASP_FUNC_CONNECT */
#if BOOTLOADER_CAN_EXIT
	stayinloader	   |= (0x01);
#endif
    }
    return len;
}

#if (USE_EXCESSIVE_ASSEMBLER) && ((!HAVE_CHIP_ERASE) || (HAVE_ONDEMAND_PAGEERASE)) && (SPM_PAGESIZE <= 256) && (((BOOTLOADER_PAGEADDR>>0)&0xff) == 0)
uchar usbFunctionWrite(uchar *data, uchar len)
{
uchar   isLast;

    DBG1(0x31, (void *)&currentAddress.l, 4);
    if(len > bytesRemaining)
        len = bytesRemaining;
    bytesRemaining -= len;
    isLast = bytesRemaining == 0;
    if(currentRequest >= USBASP_FUNC_READEEPROM){
        uchar i;
        for(i = 0; i < len; i++){
            eeprom_write_byte((void *)(currentAddress.w[0]++), *data++);
        }
    }else{
	asm  volatile  (
	  "sbrc		%[len], 0\n\t"
	  "inc		%[len]\n\t"
"usbFunctionWrite_flashloop:\n\t"
	  "subi		%[len], 2\n\t"
	  "brlo		usbFunctionWrite_finished\n\t"
	  
#if HAVE_BLB11_SOFTW_LOCKBIT
	  "cpi		r31, %[blsaddrhi]\n\t"			/* accelerated BLB11_SOFTW_LOCKBIT check */
	  "brsh		usbFunctionWrite_finished\n\t"
// 	  "brlo		usbFunctionWrite_addrunlock_ok\n\t"
// 	  "brne		usbFunctionWrite_finished\n\t"
// 	  "cpi		r30, %[blsaddrlo]\n\t"
// 	  "brlo		usbFunctionWrite_addrunlock_ok\n\t"
// 	  "rjmp		usbFunctionWrite_finished\n\t"
// "usbFunctionWrite_addrunlock_ok:\n\t"
#endif
	  "rcall	usbFunctionWrite_waitA\n\t"
	  "cli\n\t"						/* r0 or r1 may be __zero_reg__ and may become dangerous nonzero within interrupts */
	  "ld		r0,		X+\n\t"
	  "ld		r1,		X+\n\t"

	  "ldi		r18,		%[pagfillval]\n\t"
	  "rcall	usbFunctionWrite_saveflash\n\t"	/* page fill */

	  "mov		r18,		r30\n\t"
	  "subi		r18,		0xfe\n\t"		/* add with 2 */
	  "andi		r18,		%[pagemask]\n\t"
	  "breq		usbFunctionWrite_pageisfull\n\t"
	  "tst		%[islast]\n\t"
	  "breq		usbFunctionWrite_skippageisfull\n\t"
	  "tst		%[isLastPage]\n\t"
	  "breq		usbFunctionWrite_skippageisfull\n\t"
	  "cpi		%[len],		0\n\t"
	  "brne		usbFunctionWrite_skippageisfull\n\t"

"usbFunctionWrite_pageisfull:\n\t"				/* start writing the page */
	  "ldi		r18,		%[pageraseval]\n\t"
	  "rcall	usbFunctionWrite_saveflash\n\t"	/* page erase */
	  "rcall	usbFunctionWrite_waitA\n\t"

	  "ldi		r18,		%[pagwriteval]\n\t"
	  "rcall	usbFunctionWrite_saveflash\n\t"	/* page write */
	  "rcall	usbFunctionWrite_waitA\n\t"

	  "in		__tmp_reg__,	%[spmcr]\n\t"
	  "sbrs		__tmp_reg__,	%[rwwsbbit]\n\t"
	  "rjmp		usbFunctionWrite_skippageisfull\n\t"
	  "ldi		r18,		%[rwwenrval]\n\t"
	  "rcall	usbFunctionWrite_saveflash\n\t"	/* reenable rww*/
// 	  "rcall	usbFunctionWrite_waitA\n\t"


"usbFunctionWrite_skippageisfull:\n\t"	  
	  "adiw		r30,		0x2\n\t"
	  "rjmp		usbFunctionWrite_flashloop\n\t"

"usbFunctionWrite_saveflash:\n\t"
	  "cli\n\t"
	  "out		%[spmcr],	r18\n\t"
	  "spm\n\t"
	  "clr		__zero_reg__\n\t"			/* if r0 or r1 is __zero_reg__ it may have become inconsisten while page-fill */
	  "sei\n\t"
	  "ret\n\t"

"usbFunctionWrite_waitA:\n\t"
	  "in		__tmp_reg__,	%[spmcr]\n\t"
	  "sbrc		__tmp_reg__,	%[spmenbit]\n\t"
	  "rjmp		usbFunctionWrite_waitA\n\t"
	  "ret\n\t"
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

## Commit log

2020-09-21 add gerbers and readme
    [wy60_usb-B_Cu.gbr, wy60_usb-B_Mask.gbr, wy60_usb-B_Paste.gbr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]
2020-09-21 fix annotation
    [wy60_usb.sch]
2020-09-30 fixed USB orientation
    [wy60_usb.kicad_pcb]
2020-10-13 fixed spacing
    [wy60_usb-B_Cu.gbr, wy60_usb-B_Mask.gbr, wy60_usb-B_Paste.gbr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]
2020-10-15 add missing screwhole
    [wy60_usb-B_Cu.gbr, wy60_usb-B_Mask.gbr, wy60_usb-B_Paste.gbr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]
2020-10-15 fix screwhole positions
    [wy60_usb-B_Cu.gbr, wy60_usb-B_Mask.gbr, wy60_usb-B_Paste.gbr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]
2020-10-15 added JST port for fixed cable
    [wy60_usb-B_Cu.gbr, wy60_usb-B_Mask.gbr, wy60_usb-B_Paste.gbr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]
2020-10-15 add jst legends
    [wy60_usb-B_Cu.gbr, wy60_usb-B_Mask.gbr, wy60_usb-B_Paste.gbr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]

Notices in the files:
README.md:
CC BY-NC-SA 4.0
